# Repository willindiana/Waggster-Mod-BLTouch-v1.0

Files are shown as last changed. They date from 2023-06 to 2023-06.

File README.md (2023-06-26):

# Waggster-Mod-BLTouch-v1.0
Note this is just a repost of the files originally located at https://3duk.co.uk which at the time of posting are no longer available.

Video Guide provided here: https://youtu.be/ynm8inRMVkE

There should be a v1.1 floating around somewhere if you have a clone of this, please open an issue and provide access to the source so I can upload that as well.

Please note I did not write this code in this repo or maintain it all credit goes to Waggster. I only am providing this mirror as I am unable to find it anywhere else online.

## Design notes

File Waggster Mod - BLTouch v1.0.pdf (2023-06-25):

Artillery Sidewinder BLTouch v1.0 | Waggster Mod

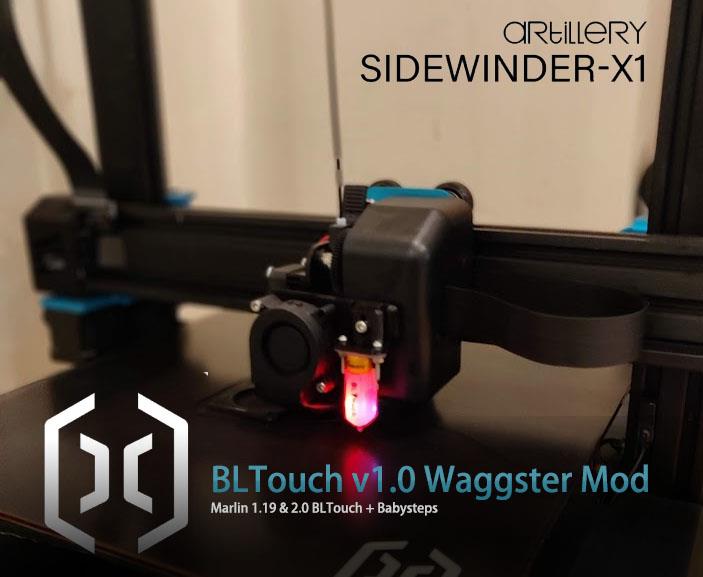
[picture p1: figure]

1 | P a g e

## BLTouch v1.0 Waggster Mod

## Includes

Wireless BLTouch wireless mod MKS Gen L1.0 Marlin 1.19 / 2.0 Firmware (recommended) MKS 2.8 TFT LCD Firmware
PrusaSlicer Profiles

by Steve Wagg
(CdRsKuLL)

## REMEMBER TO REMOVE THE POWER CABLE

## What’s this mod all about?

This mod will enable you to attach a BLTouch using the existing LCD pins on the Artillery Sidewinder Pro X1. You will need to take the printer apart and relocate two cables which are the 3 pin and a 1 pin cable.

Items required

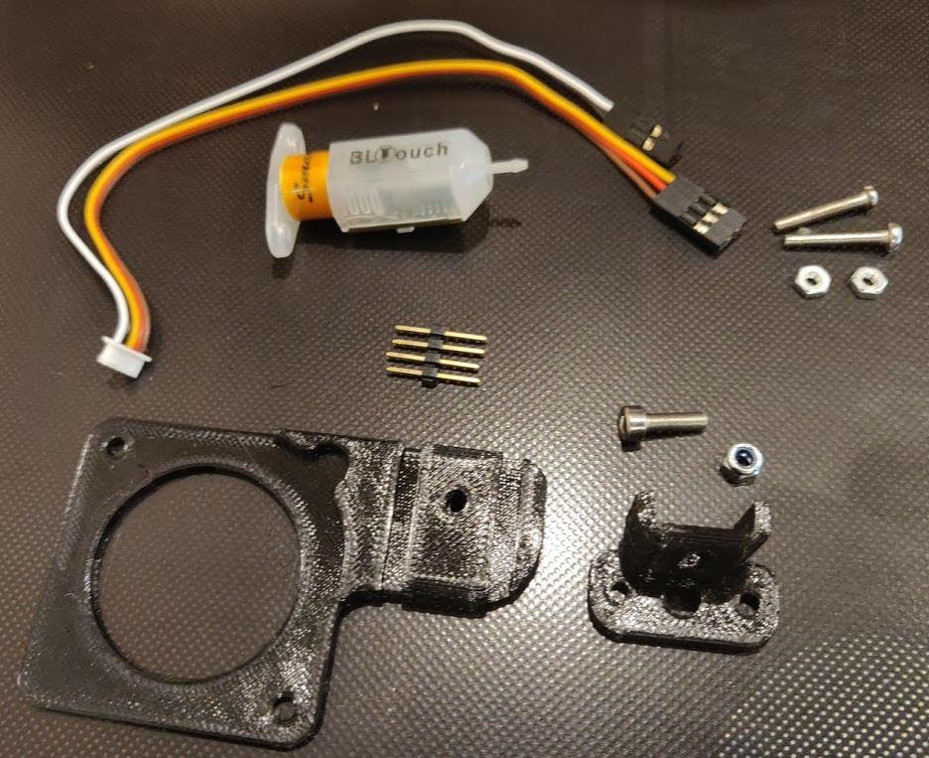
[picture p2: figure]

3D parts, BLTouch, 2 x mounting screws, 1 x M3x10 caphead screw with nyloc nut, 4 pin connector

## REMEMBER TO REMOVE THE POWER CABLE

Index

Mainboard LED cables relocation | page 3
BLTouch wiring | page 5
Mainboard firmware update | page 7
LCD firmware update | page 8
Setup BLTouch | page 9
Set your Z-Offset (part 1) | page 10
Autolevel G29 | page 11
Babysteps - Live Z-Offset adjust (part 2) | page 12

## Internal LED Cables

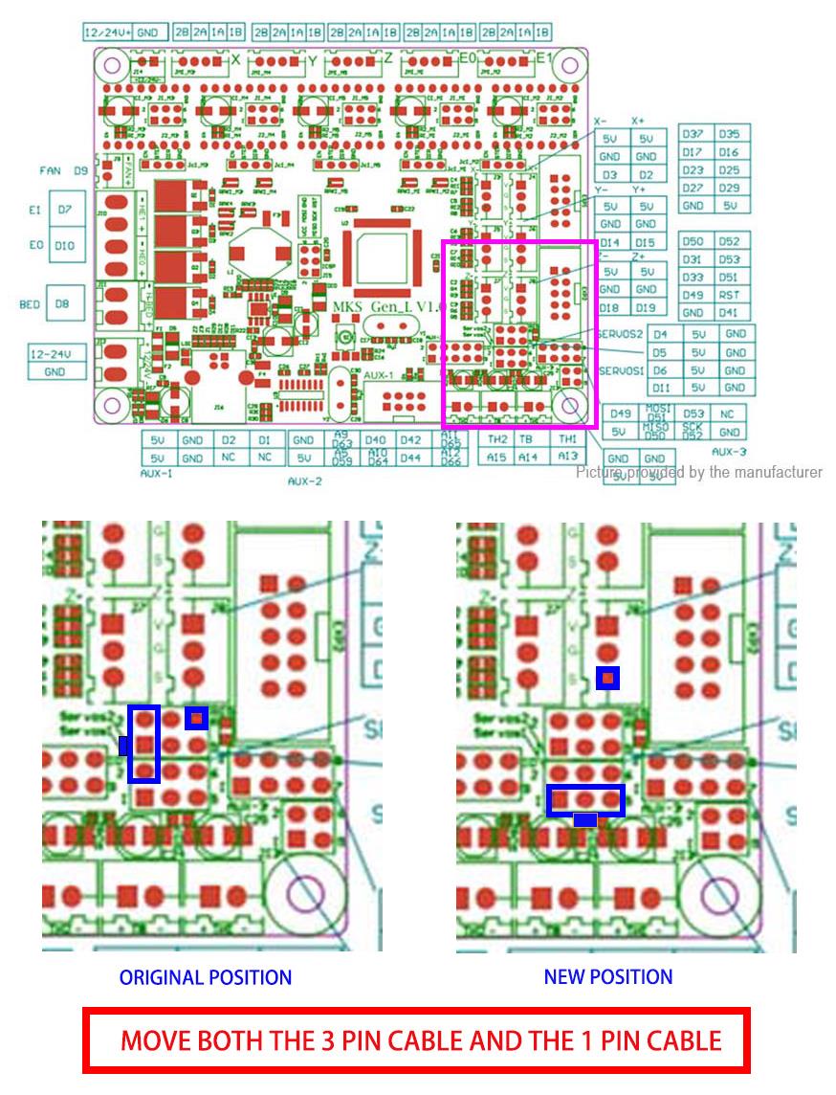
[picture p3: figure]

## Internal LED Cables

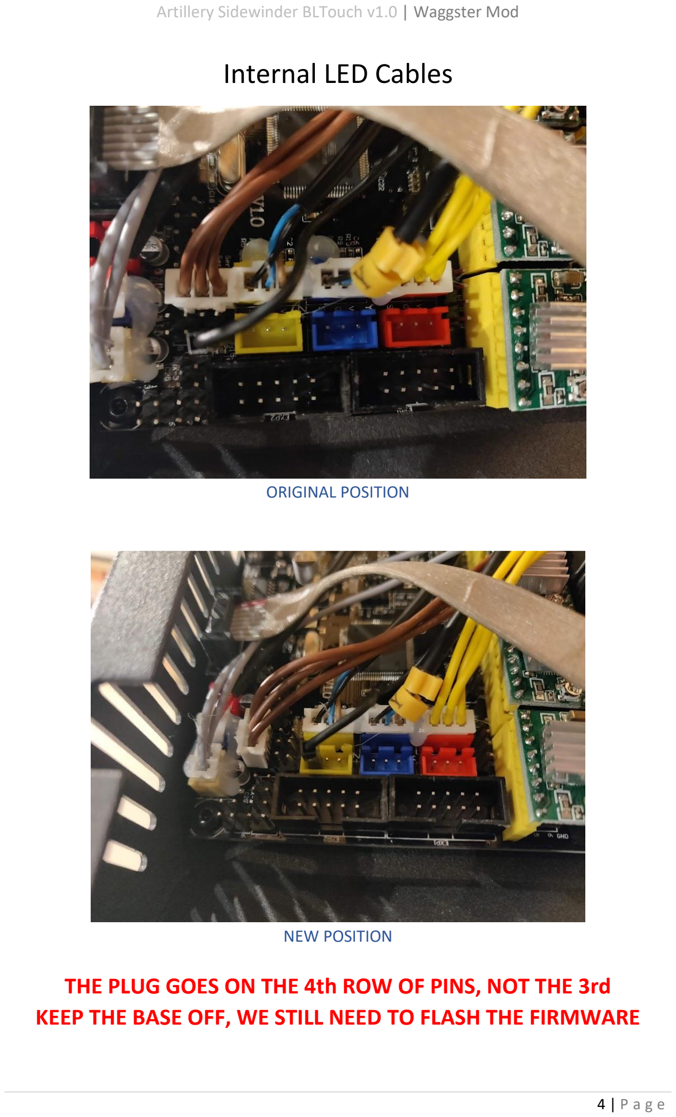
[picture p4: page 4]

ORIGINAL POSITION

NEW POSITION

## THE PLUG GOES ON THE 4th ROW OF PINS, NOT THE 3rd KEEP THE BASE OFF, WE STILL NEED TO FLASH THE FIRMWARE

## External LED BLTouch connection

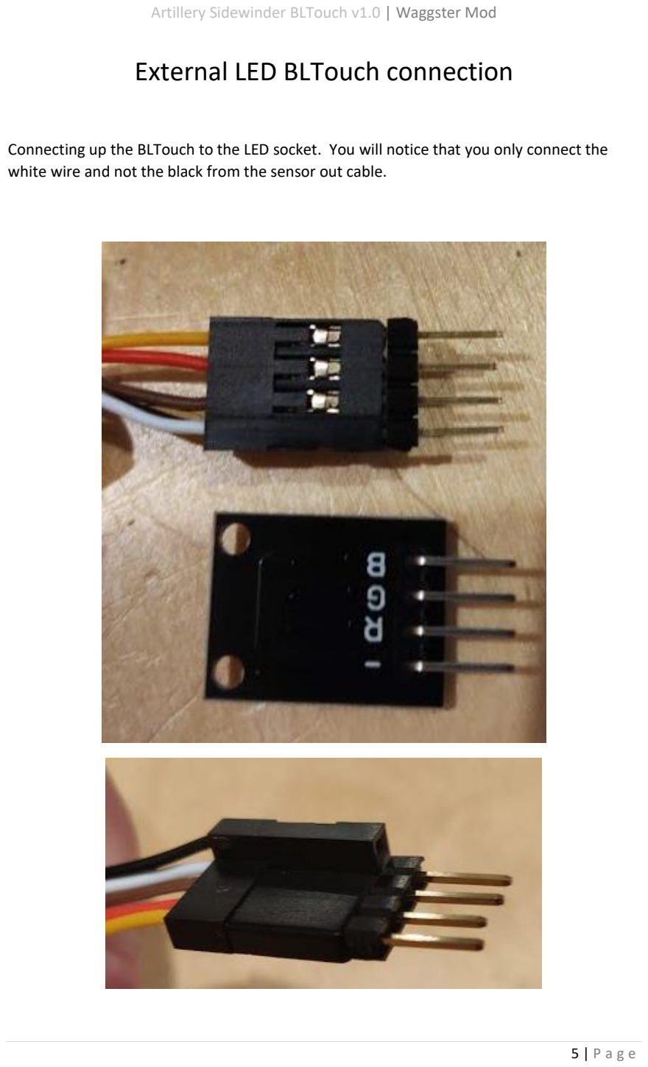
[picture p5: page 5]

Connecting up the BLTouch to the LED socket. You will notice that you only connect the white wire and not the black from the sensor out cable.

## External LED BLTouch connection

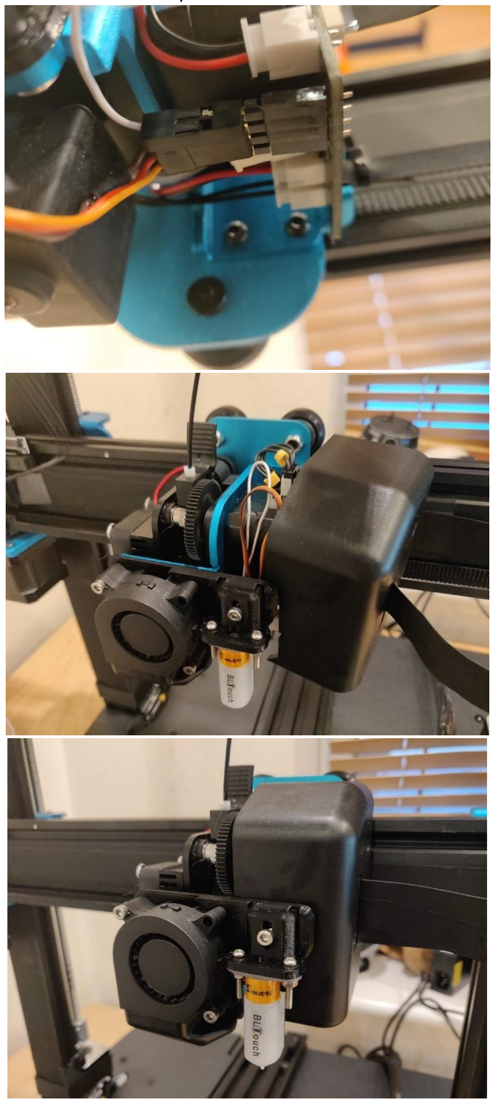
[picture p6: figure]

Complete the installation

## Flashing the mainboard firmware

Download and install Prusa Slicer 2.0 from https://www.prusa3d.com/drivers/
Click on the link that looks like this

Unplug the LCD screen from the mainboard

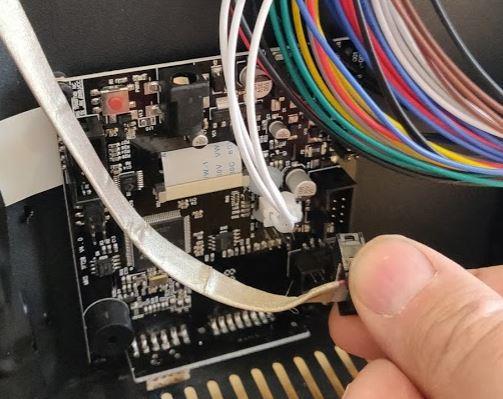
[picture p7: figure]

Connect your printer up via the USB lead, the printer power does NOT need to be on.

Start up Prusa Slicer 2.0 and select Configuration … Firmware Flasher and the below screen will appear.

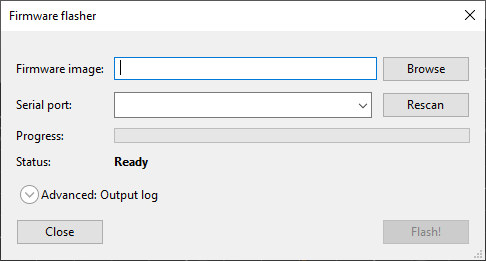
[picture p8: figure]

Select the serial port and choose either the Marlin 1.1.9 or Marlin 2.0 HEX file from the folder ‘Firmware - Main Board’. I’m running 2.0 without a problem (newest), so give that a go first.

## Flashing the LCD firmware

Once you have flashed the mainboard firmware then reconnect the LCD ribbon cable. Remove the USB cable and refit the base. Once back in one piece then plug the printer back in but do NOT turn it on yet.

Copy the files from the ‘Firmware - LCD Touchscreen’ folder into the root of a micro SD card.

Insert the card and turn the machine on. It will beep and start updating the LCD touchscreen. This takes about a minute and will look something like the below.

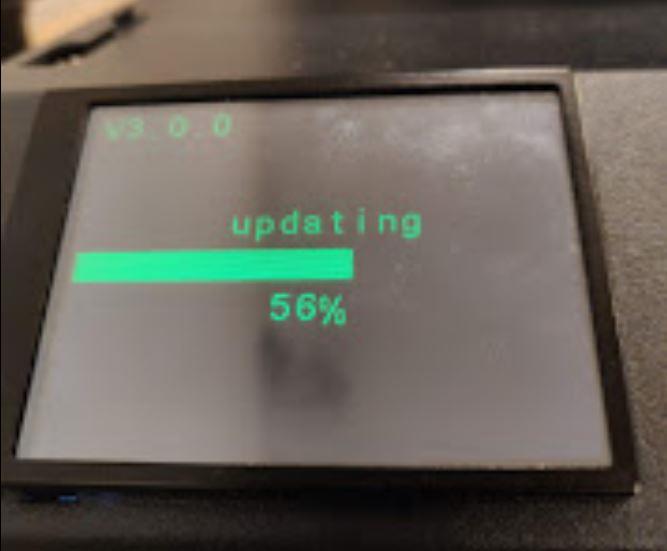
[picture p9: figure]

## IMPORTANT - ONCE COMPLETE YOU MUST RESET THE EEPROM Press Tools … More … Reset Eeprom

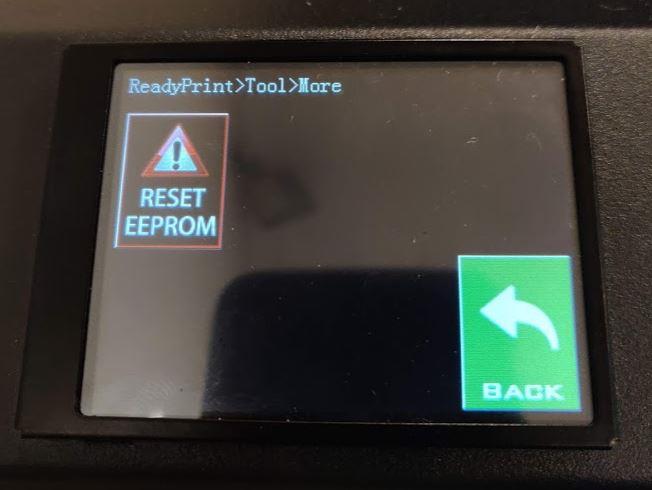
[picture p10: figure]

## Don’t forget to set the default FILE location back to USB… Click ‘SET’..’FILE’..’USB’

## Setup and using

Make sure you have flashed the mainboard and the touchscreen firmware. Once happy then you will need to set the height of the BLTouch.

Setting the height of the BLTouch

1. Move the BLTouch all the way down on its mount to start with (closer to the bed) and tighten up the height screw.
2. Power the machine on and select home from the LCD menu. (lower the Z axis)
3. Power off the machine, undo the BLTouch height screw and move it up to the top.
4. With the printer powered off, rotate both the Z axis motors and lower the nozzle until it touches the bed.
5. Put the 3mm calibration 3d printed part under the BLTouch and lower it until it touches the printed part.
6. Tighten up the height adjustment screw. Your BLTouch will now be 3mm above the nozzle when retracted. Then, raise the nozzle a few mm’s away so you don’t damage your bed by twisting the motors again.

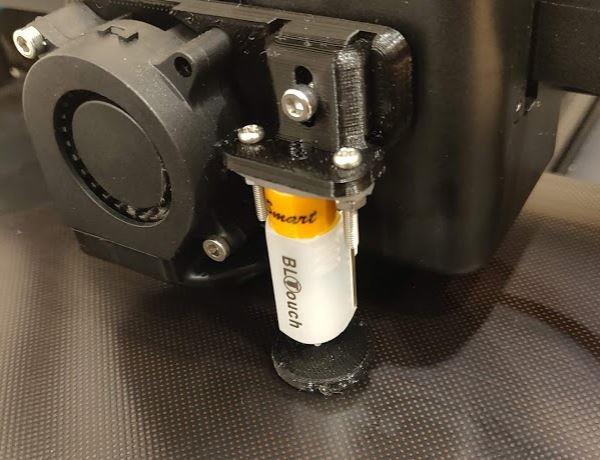
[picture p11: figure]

## Setting your Z-Offset (part 1)

I’ve tried to make this as easy as possible. You can set the Z-Offset completely from the touchscreen. After you have set the height of your BLTouch from the previous page you need to set the Z-Offset. This is the distance from the trigger point on the BLTouch to the bottom of the nozzle.

1. Turn the printer on.
2. Press ‘Tools’ then the ‘More’ button
3. If you haven’t done already then press the ‘RESET EEPROM’. You need to do this because you have updated the mainboard firmware, most likely to a different version.
4. Press the ‘START Z-OFFEST’
5. Use a piece of paper and adjust the nozzle height by pressing the up and down buttons.
6. Once you can feel it grabbing the paper then remove the paper and press the ‘MOVE DOWN’ button TWO MORE TIMES. Press back

Your Z-Offset height will now be set.

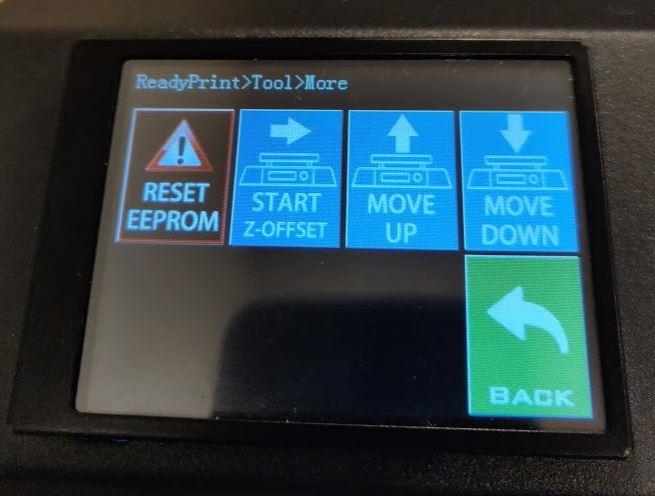
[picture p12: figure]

## Autolevel (G29)

Now you have added a BLTouch you can run an autolevel routine before every print. This is quite easy to do with a simple G29 command. Depending which slicer you use you will need to edit the Start GCODE script. Make sure you add it AFTER the G28; If you are using the included Prusa profile, then this has already been done. You can also run this from the LCD menu and it will remember the mesh recorded.

In Cura you add the G29 in the Machine Settings page

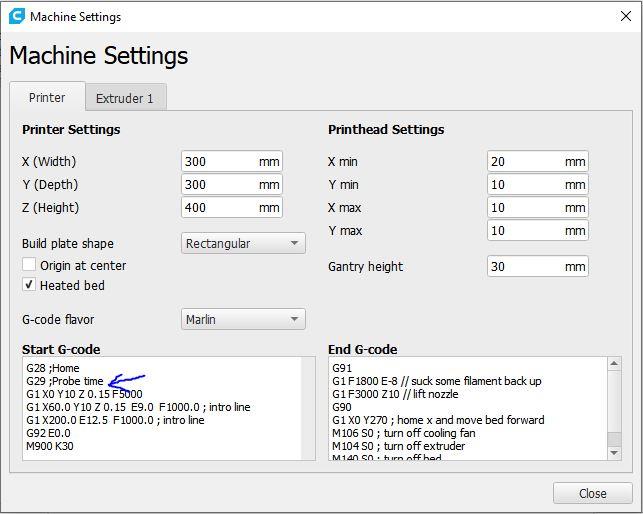
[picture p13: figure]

In Simplify3D you add the G29 in the FFF settings

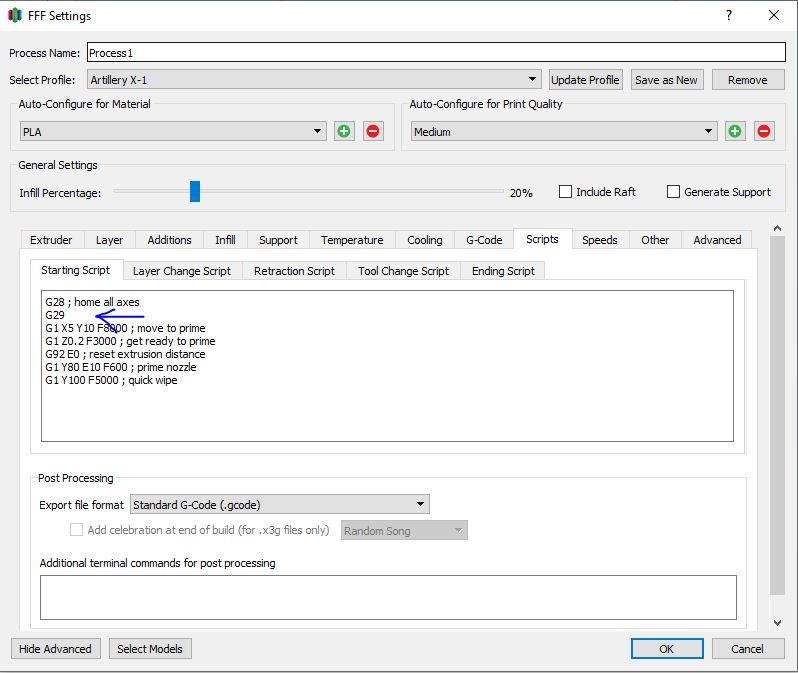
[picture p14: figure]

## Babysteps -Live Z-Offset adjust (part 2)

Babysteps is a bit of a fancy name but we will be using it for live Z-offset adjust. This function allows you to alter your first layer height LIVE, as it’s printing. It’s really easy to use and it will save your settings ready for your next print so you will not have to do it each time.

1. Start a print with a large 1st layer. Make sure you have sliced it using the G29 auto level command as on the previous page.
2. When it starts printing press the ‘OPTIONS’ then ‘MORE’ button.
3. Adjust the Z-Offset height if you need to by the UP / DOWN buttons. It autosaves the position. Be careful not to lower the nozzle to much as it will damage your bed.

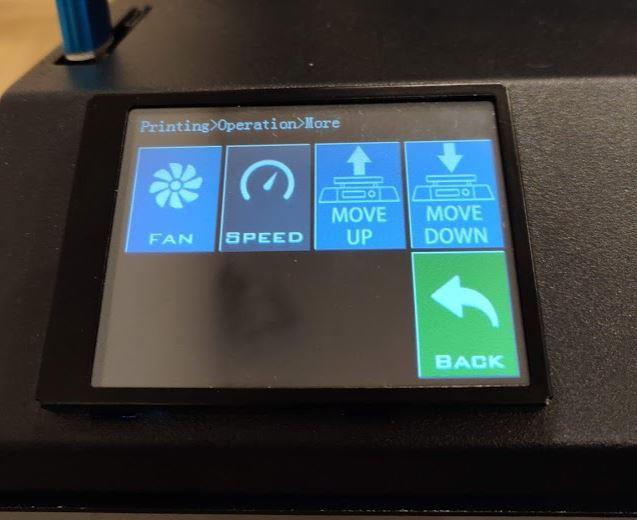
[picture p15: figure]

Babysteps adjustment

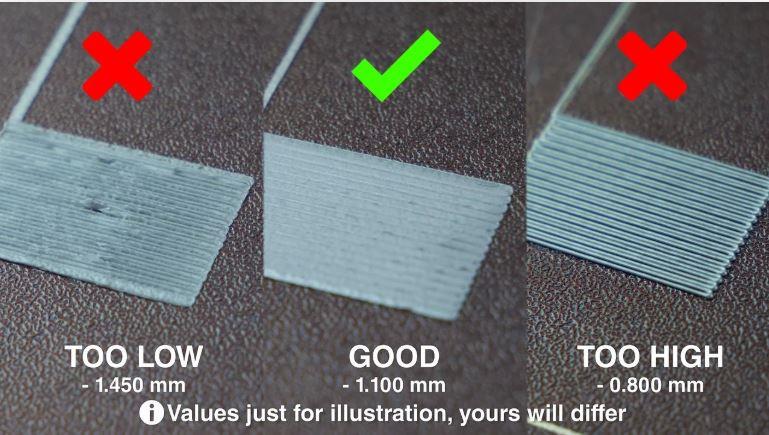
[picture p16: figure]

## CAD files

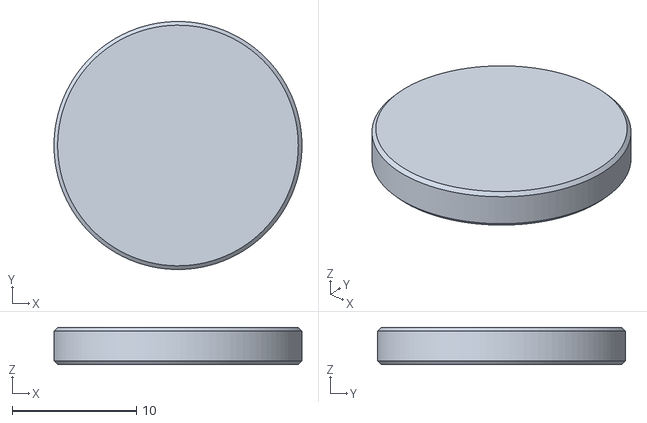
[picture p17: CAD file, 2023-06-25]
STL Files/BLTouch Calibration.stl
20.0 x 20.0 x 3.00

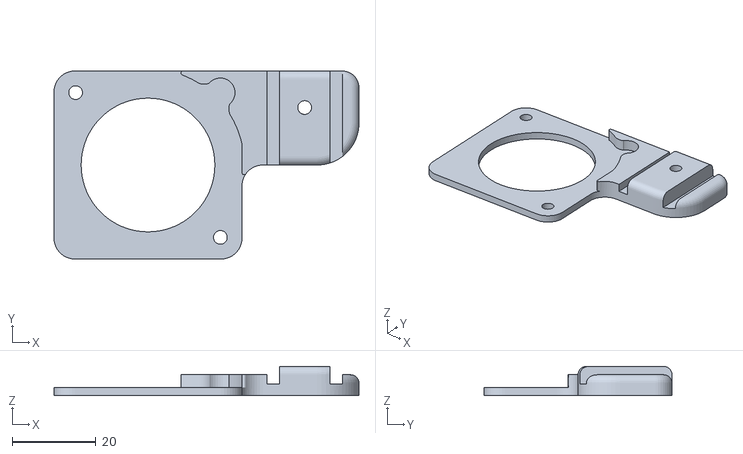
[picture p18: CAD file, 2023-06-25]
STL Files/BLTouch Mount Adjustable.stl
73.0 x 45.0 x 7.00

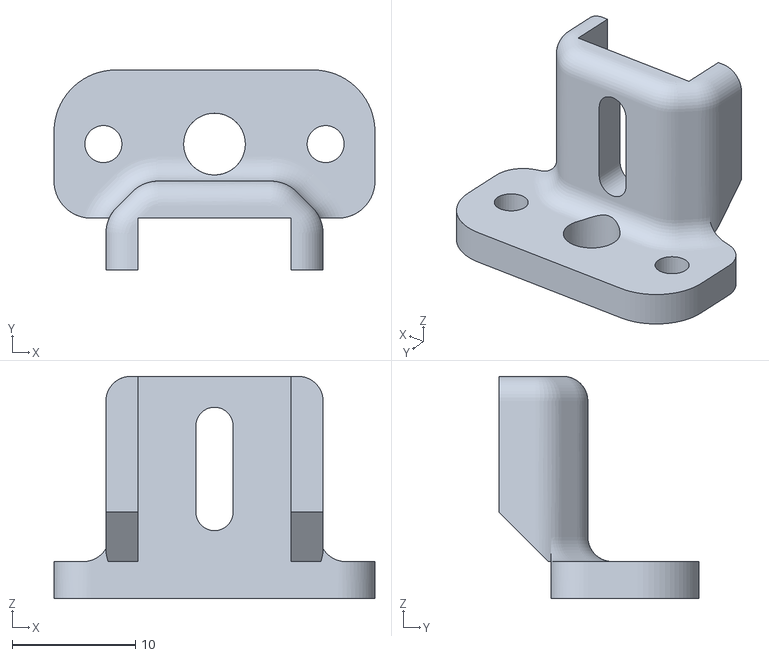
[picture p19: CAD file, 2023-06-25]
STL Files/BLTouch Mount Slider.stl
26.0 x 16.2 x 18.0

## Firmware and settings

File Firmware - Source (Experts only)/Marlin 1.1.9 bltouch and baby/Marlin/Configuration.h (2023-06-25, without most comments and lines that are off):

#define CONFIGURATION_H
#define CONFIGURATION_H_VERSION 010109
#define STRING_CONFIG_H_AUTHOR "Steve Wagg (CdRsKuLL) @ https://pretendprusa.co.uk)" // Who made the changes.
#define SERIAL_PORT 0
#define BAUDRATE 250000
  #define MOTHERBOARD BOARD_MKS_GEN_L
#define EXTRUDERS 1
#define DEFAULT_NOMINAL_FILAMENT_DIA 1.75
#define POWER_SUPPLY 0
#define TEMP_SENSOR_0 1
#define TEMP_SENSOR_1 0
#define TEMP_SENSOR_2 0
#define TEMP_SENSOR_3 0
#define TEMP_SENSOR_4 0
#define TEMP_SENSOR_BED 1
#define TEMP_SENSOR_CHAMBER 0
#define DUMMY_THERMISTOR_998_VALUE 25
#define DUMMY_THERMISTOR_999_VALUE 100
#define MAX_REDUNDANT_TEMP_SENSOR_DIFF 10
#define TEMP_RESIDENCY_TIME 10  // (seconds)
#define TEMP_HYSTERESIS 5       // (degC) range of +/- temperatures considered "close" to the target one
#define TEMP_WINDOW     1       // (degC) Window around target to start the residency timer x degC early.
#define TEMP_BED_RESIDENCY_TIME 10  // (seconds)
#define TEMP_BED_HYSTERESIS 3       // (degC) range of +/- temperatures considered "close" to the target one
#define TEMP_BED_WINDOW     1       // (degC) Window around target to start the residency timer x degC early.
#define HEATER_0_MINTEMP 5
#define HEATER_1_MINTEMP 5
#define HEATER_2_MINTEMP 5
#define HEATER_3_MINTEMP 5
#define HEATER_4_MINTEMP 5
#define BED_MINTEMP 5
#define HEATER_0_MAXTEMP 275
#define HEATER_1_MAXTEMP 275
#define HEATER_2_MAXTEMP 275
#define HEATER_3_MAXTEMP 275
#define HEATER_4_MAXTEMP 275
#define BED_MAXTEMP 150
#define PIDTEMP
#define BANG_MAX 255     // Limits current to nozzle while in bang-bang mode; 255=full current
#define PID_MAX BANG_MAX // Limits current to nozzle while PID is active (see PID_FUNCTIONAL_RANGE below); 255=full current
#define PID_K1 0.95      // Smoothing factor within any PID loop
  #define PID_FUNCTIONAL_RANGE 10 // If the temperature difference between the target temperature and the actual temperature
  #define DEFAULT_Kp 14.58
  #define DEFAULT_Ki 1.14
  #define DEFAULT_Kd 46.57
#define PIDTEMPBED
#define MAX_BED_POWER 255 // limits duty cycle to bed; 255=full current
  #define DEFAULT_bedKp 244.21
  #define DEFAULT_bedKi 45.87
  #define DEFAULT_bedKd 325.08
#define PREVENT_COLD_EXTRUSION
#define EXTRUDE_MINTEMP 170
#define PREVENT_LENGTHY_EXTRUDE
#define EXTRUDE_MAXLENGTH 200
#define THERMAL_PROTECTION_HOTENDS // Enable thermal protection for all extruders
#define THERMAL_PROTECTION_BED     // Enable thermal protection for the heated bed
#define USE_XMIN_PLUG
#define USE_YMIN_PLUG
#define USE_ZMIN_PLUG
#define ENDSTOPPULLUPS
#define X_MIN_ENDSTOP_INVERTING true // set to true to invert the logic of the endstop.
#define Y_MIN_ENDSTOP_INVERTING true // set to true to invert the logic of the endstop.
#define Z_MIN_ENDSTOP_INVERTING false // set to true to invert the logic of the endstop.
#define X_MAX_ENDSTOP_INVERTING false // set to true to invert the logic of the endstop.
#define Y_MAX_ENDSTOP_INVERTING false // set to true to invert the logic of the endstop.
#define Z_MAX_ENDSTOP_INVERTING false // set to true to invert the logic of the endstop.
#define Z_MIN_PROBE_ENDSTOP_INVERTING false // set to true to invert the logic of the probe.
#define X_DRIVER_TYPE  TMC2100
#define Y_DRIVER_TYPE  TMC2100
#define Z_DRIVER_TYPE  TMC2100
#define Z2_DRIVER_TYPE TMC2100
#define E0_DRIVER_TYPE TMC2100
#define ENDSTOP_NOISE_FILTER
#define DEFAULT_AXIS_STEPS_PER_UNIT   { 80.121, 80.121, 399.778, 445 }
#define DEFAULT_MAX_FEEDRATE          { 300, 300, 50, 40 }
#define DEFAULT_MAX_ACCELERATION      { 2000, 2000, 100, 10000 }
#define DEFAULT_ACCELERATION          800    // X, Y, Z and E acceleration for printing moves
#define DEFAULT_RETRACT_ACCELERATION  10000    // E acceleration for retracts
#define DEFAULT_TRAVEL_ACCELERATION   2000    // X, Y, Z acceleration for travel (non printing) moves
#define DEFAULT_XJERK                 8.0
#define DEFAULT_YJERK                 8.0
#define DEFAULT_ZJERK                 0.3
#define DEFAULT_EJERK                 5.0
#define S_CURVE_ACCELERATION
#define Z_MIN_PROBE_USES_Z_MIN_ENDSTOP_PIN
#define BLTOUCH
#define X_PROBE_OFFSET_FROM_EXTRUDER 28  // X offset: -left  +right  [of the nozzle]
#define Y_PROBE_OFFSET_FROM_EXTRUDER -33 // Y offset: -front +behind [the nozzle]
#define Z_PROBE_OFFSET_FROM_EXTRUDER 0   // Z offset: -below +above  [the nozzle]
#define MIN_PROBE_EDGE 10
#define XY_PROBE_SPEED 8000
#define Z_PROBE_SPEED_FAST HOMING_FEEDRATE_Z
#define Z_PROBE_SPEED_SLOW (Z_PROBE_SPEED_FAST / 2)
#define Z_CLEARANCE_DEPLOY_PROBE   15 // Z Clearance for Deploy/Stow
#define Z_CLEARANCE_BETWEEN_PROBES  5 // Z Clearance between probe points
#define Z_CLEARANCE_MULTI_PROBE     5 // Z Clearance between multiple probes
#define Z_AFTER_PROBING            15 // Z position after probing is done
#define Z_PROBE_LOW_POINT          -2 // Farthest distance below the trigger-point to go before stopping
#define Z_PROBE_OFFSET_RANGE_MIN -20
#define Z_PROBE_OFFSET_RANGE_MAX 20
#define X_ENABLE_ON 0
#define Y_ENABLE_ON 0
#define Z_ENABLE_ON 0
#define E_ENABLE_ON 0 // For all extruders
#define DISABLE_X false
#define DISABLE_Y false
#define DISABLE_Z false
#define DISABLE_E false // For all extruders
#define DISABLE_INACTIVE_EXTRUDER true // Keep only the active extruder enabled.
#define INVERT_X_DIR false
#define INVERT_Y_DIR false
#define INVERT_Z_DIR true
#define INVERT_E0_DIR false
#define INVERT_E1_DIR false
#define INVERT_E2_DIR false
#define INVERT_E3_DIR false
#define INVERT_E4_DIR false
#define X_HOME_DIR -1
#define Y_HOME_DIR -1
#define Z_HOME_DIR -1
#define X_BED_SIZE 300
#define Y_BED_SIZE 310
#define X_MIN_POS -2
#define Y_MIN_POS -5
#define Z_MIN_POS 0
#define X_MAX_POS X_BED_SIZE
#define Y_MAX_POS Y_BED_SIZE
#define Z_MAX_POS 400
#define MIN_SOFTWARE_ENDSTOPS
  #define MIN_SOFTWARE_ENDSTOP_X
  #define MIN_SOFTWARE_ENDSTOP_Y
  #define MIN_SOFTWARE_ENDSTOP_Z
#define MAX_SOFTWARE_ENDSTOPS
  #define MAX_SOFTWARE_ENDSTOP_X
  #define MAX_SOFTWARE_ENDSTOP_Y
  #define MAX_SOFTWARE_ENDSTOP_Z
#define AUTO_BED_LEVELING_BILINEAR
#define RESTORE_LEVELING_AFTER_G28
  #define ENABLE_LEVELING_FADE_HEIGHT
  #define SEGMENT_LEVELED_MOVES
  #define LEVELED_SEGMENT_LENGTH 5.0 // (mm) Length of all segments (except the last one)
  #define GRID_MAX_POINTS_X 5
  #define GRID_MAX_POINTS_Y GRID_MAX_POINTS_X
#define Z_SAFE_HOMING
  #define Z_SAFE_HOMING_X_POINT ((X_BED_SIZE) / 2)    // X point for Z homing when homing all axes (G28).
  #define Z_SAFE_HOMING_Y_POINT ((Y_BED_SIZE) / 2)    // Y point for Z homing when homing all axes (G28).
#define HOMING_FEEDRATE_XY (60*60)
#define HOMING_FEEDRATE_Z  (16*60)
#define EEPROM_SETTINGS // Enable for M500 and M501 commands
#define EEPROM_CHITCHAT   // Give feedback on EEPROM commands. Disable to save PROGMEM.
#define HOST_KEEPALIVE_FEATURE        // Disable this if your host doesn't like keepalive messages
#define DEFAULT_KEEPALIVE_INTERVAL 2  // Number of seconds between "busy" messages. Set with M113.
#define BUSY_WHILE_HEATING            // Some hosts require "busy" messages even during heating
#define PREHEAT_1_TEMP_HOTEND 210
#define PREHEAT_1_TEMP_BED     60
#define PREHEAT_1_FAN_SPEED     0 // Value from 0 to 255
#define PREHEAT_2_TEMP_HOTEND 240
#define PREHEAT_2_TEMP_BED    110
#define PREHEAT_2_FAN_SPEED     0 // Value from 0 to 255
#define PRINTJOB_TIMER_AUTOSTART
#define LCD_LANGUAGE en
#define DISPLAY_CHARSET_HD44780 JAPANESE
#define SPEAKER
#define LCD_FEEDBACK_FREQUENCY_DURATION_MS 2
#define LCD_FEEDBACK_FREQUENCY_HZ 5000
#define SOFT_PWM_SCALE 0
#define SERVO_DELAY { 300 }

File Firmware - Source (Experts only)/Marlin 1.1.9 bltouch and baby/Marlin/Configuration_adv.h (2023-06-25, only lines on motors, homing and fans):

#define E0_AUTO_FAN_PIN 7
#define E1_AUTO_FAN_PIN -1
#define E2_AUTO_FAN_PIN -1
#define E3_AUTO_FAN_PIN -1
#define E4_AUTO_FAN_PIN -1
#define CHAMBER_AUTO_FAN_PIN -1
#define Z_DUAL_STEPPER_DRIVERS
#define X_HOME_BUMP_MM 5
#define Y_HOME_BUMP_MM 5
#define Z_HOME_BUMP_MM 2
#define HOMING_BUMP_DIVISOR { 2, 2, 4 }  // Re-Bump Speed Divisor (Divides the Homing Feedrate)
#define MICROSTEP_MODES { 16, 16, 16, 16, 16 } // [1,2,4,8,16]
#define DIGIPOT_I2C_MOTOR_CURRENTS { 1.0, 1.0, 1.0, 1.0, 1.0, 1.0, 1.0, 1.0 }  //  AZTEEG_X3_PRO

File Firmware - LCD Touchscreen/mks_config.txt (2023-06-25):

#--------------------------------------------------------------------
#########  Printer type setting  ##################################

#mainboard firmware setting(marlin:1; repetier:2; smoothie:3)
>cfg_firmware_type:1

#machine setting (Normal:1; Delta:2)
>cfg_machine_type:1

#baud rate (9600:1; 57600:2; 115200:3; 250000:4)
>cfg_baud_rate:4

#multi-language(enable:1, disable:0)
>cfg_multiple_language:0

#languages setting
#(simplified Chinese:1; traditional Chinese:2; English:3; Russian:4; Spanish:5). This configuration is valid when "cfg_multiple_language" is disabled.
>cfg_language_type:3

#extruder number(one:1; dual:2)
>cfg_sprayer_counter:1

#enable heated bed(yes:1; no: 0)
>cfg_custom_bed_flag:1

#the max target temp of extruder and heated bed
>cfg_max_sprayer_temperature:270
>cfg_max_hotbed_temperature:150

#pause position (-1 is invalid; Z-axis is relative position)
>cfg_XPOS:-1
>cfg_YPOS:-1
>cfg_ZADD:10

#-----------------------------------------------------------------------
#########  Advanced Function Option  ##################################

#enable UPS?(yes:1; no:0)
>cfg_have_ups_device:0

#enable power detecting module(mks 220det:1; mks pwc:0)
>cfg_insert_det_module:0

#enable auto off after print finish function (no:0; Yes:1）
>cfg_print_finish_close_Machine:0

#set PB0 signal when use it for sencond nozzle (high level:1; low level:0)
>cfg_PB0_trigger_Level:0

#set PB1 signal (high level:1; low level:0)
>cfg_PB1_trigger_Level:0

#set error range of Z-axis on breakpoints recovery 
>cfg_breakpoint_z_error:0.2

#---------------------------------------------------------------------------

#########  Filament Change Function  ##############################

#the speed to extrude filament(mm/min)
>cfg_filament_load_speed:400
#the lenght to extrude filament (mm)
>cfg_filament_load_length:100

#the speed to retract filament(mm/min)
>cfg_filament_unload_speed:2000
#the lenght to retract filament(mm)
>cfg_filament_unload_length:100

#It is the minimum temperature for filament change.
It will auto heat up if the current temp doesn't reach the target.
>cfg_filament_load_limit_temperature:200

#The length of Load filament before unloader filament. 
>cfg_unload_retract_length:5

#The speed of load filament  before unloader filament.
>cfg_unload_retract_speed:500

#---------------------------------------------------------------------------

############  Leveling Function  ########################################

#leveling mode(manual:0; auto:1; conceal leveling button:2)
>cfg_leveling_mode:1

#the command of auto leveling (G29 is available for Marlin.While G32 is for  Repetier and Smoothieware)
>cfg_auto_leveling_cmd:G28;G29;

#the point number of manual leveling:(3,4,5 point available)
>cfg_point_number:5

#the coordinates of 5 point on manual leveling
>cfg_point1:50,50
>cfg_point2:250,50
>cfg_point3:250,250
>cfg_point4:50,250
>cfg_point5:150,150

#the travel speed of leveling(mm/min)
>cfg_leveling_z_speed:1500
>cfg_leveling_xy_speed:8000

#---------------------------------------------------------------------------
 
#############  WIFI Function  ##########################################

#wifi model(MKS WIFI TFT:0;  MKS HLK-WIFI:1)
>cfg_wifi_type:0

#wifi mode(0:sta;1:ap)
>cfg_wifi_mode:1

#wifi name and password
>cfg_wifi_ap_name:Artillery
>cfg_wifi_key_code:12345678

#0:disable cloud service 1:enable cloud service
>cfg_cloud_enable:0
#cloud service adress
>cfg_wifi_cloud_host:www.baizhongyun.cn
#cloud service port
>cfg_cloud_port:10086

#Dynamic access IP
>cfg_ip_dhcp_flag:1

#IP/mask/gateway
>cfg_ip_address:192.168.3.100
>cfg_ip_mask:255.255.255.0
>cfg_ip_gate:192.168.3.1

#--------------------------------------------------------------------------------

############## Function Customization #######################################

#user-defined function1 and 2.(display this button .  disable: 0; enable: 1)
>cfg_function_btn1_display:1

#command of user-defined function
>function_btn1_cmd:M84;

#set number of  "More" button 
>moreitem_pic_cnt:5

#edit command for 1~7 "More" button,each command must be separated by semicolon ";"
>moreitem_button1_cmd:M502; M500; 

>moreitem_button2_cmd:G28; G91; G0 X28 Y-33; G90; G1 Z0;

>moreitem_button3_cmd:M290 Z0.025; M500;

>moreitem_button4_cmd:M290 Z-0.025; M500;

>moreitem_button5_cmd:M280 P0 S60; G4 P500; M280 P0 S90; G4 P200

>moreitem_button6_cmd:G28;

>moreitem_button7_cmd:G28;


#how many "More" button display on screen interface
>morefunc_cnt:2

#command setting on button1~6
>morefunc1_cmd:M290 Z0.025; M500;
>morefunc2_cmd:M290 Z-0.025; M500;
>morefunc3_cmd:G28;
>morefunc4_cmd:G28;
>morefunc6_cmd:G28;

#---------------------------------------------------------------------------------
##### Display Customization(button and logo customized see User's Manual) #######

#the color of screen background
>cfg_background_color:0x000000

#the color of title text
>cfg_title_color:0xFFFFFF
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

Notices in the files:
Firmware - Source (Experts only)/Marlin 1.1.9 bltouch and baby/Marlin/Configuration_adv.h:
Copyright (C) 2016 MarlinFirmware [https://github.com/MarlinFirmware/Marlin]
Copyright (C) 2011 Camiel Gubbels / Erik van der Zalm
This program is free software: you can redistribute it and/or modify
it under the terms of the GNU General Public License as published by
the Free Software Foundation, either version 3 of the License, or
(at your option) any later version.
